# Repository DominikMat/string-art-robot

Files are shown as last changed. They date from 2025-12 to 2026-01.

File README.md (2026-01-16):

# String Art Robot

A machine to automatically draw string art designs on a circular ring of nails.

## Project Overview

**Team Members:** 
- Dominik Matuszczyk (PL)
- Dizha Oleksii (UA) 
- Tkachuk Nikita (UA)

This robot was created for the Intro to Robotics course at the University of the Aegean (Fall Semester 2025/26) during our Erasmus trips. 
The system uses a computer-generated sequence to physically wind string around a ring of nails to create geometric patterns.

---

## Links & Media
To see our creation you can view our presentation file or our video presentation (made because of bad weather on Samos island on the day of class)
* Project Presentation: https://docs.google.com/presentation/d/1VIfVSTO9Wcaq9Rl0Zi-_Bw-y_5G3Nwj30t2qu21ZTrM/edit?usp=sharing
* Demo Video: https://drive.google.com/file/d/1XwlmAQR4rs1_c6xqZL0Uokjqz6scIsDI/view?usp=drivesdk
* Demo Video YouTube (if above not working): https://youtu.be/TUs5X3Doydk
---

## 🔌 Hardware Wiring
The wiring involves connecting the Servo directly to the Pico and the Stepper Motor via the ULN2003 driver chip.

### Wiring Diagram Table

| Servo connections | Servo Wire colour | Pico Pin | Description |
| :--- | :--- | :--- | :--- |
| (MG996R) | Orange (Signal) | Pico GP16 | PWM Control |
| | Red (VCC) | Pico VBUS | 5V Power |
| | Brown (GND) | Pico GND | Ground |

| Stepper Driver chip connections | ULM Chip Input | Pico Pin | Description |
| :--- | :--- | :--- | :--- |
| (ULN2003) | Pin 1 (IN1) | GP18 | Input for Coil A |
| (Pico to Driver)| Pin 2 (IN2) | GP19 | Input for Coil B |
| | Pin 3 (IN3) | GP20 | Input for Coil C |
| | Pin 4 (IN4) | GP21 | Input for Coil D |
| | Pin 8 (-) | GND | Ground |
| | Pin 9 (+) | VBUS | 5V Power |

| Stepper Motor connections | Stepper Wire colour | ULM Chip Output | Description |
| :--- | :--- | :--- | :--- |
| (28BYJ-48) | Blue | Pin 16 (OUT1) | Coil A |
| (Stepper to driver) | Pink | Pin 15 (OUT2) | Coil B |
| | Yellow | Pin 14 (OUT3) | Coil C |
| | Orange | Pin 13 (OUT4) | Coil D |
| | Red | Pico VBUS | 5V Power |

---

## 🛠️ Software Installation & Setup

To run the robot, you need to set up the PlatformIO environment in VS Code.

### Step 1: Install VS Code & PlatformIO
1. Download and install Visual Studio Code.
2. Open VS Code, go to the Extensions tab (Ctrl+Shift+X).
3. Search for "PlatformIO IDE" and click Install.
4. Restart VS Code once the installation is complete.

### Step 2: Import / Create the Project
To be able to flash the code you can either import or create a PlatformIO project.

IMPORT
1. Download this repository and unzip
2. In the VS Code extension bar click PlatformIO (alien) icon
3. Navigate to Quick Access / PIO Home / Open and click
4. Click the 'Import Arduino Project' Button
5. Choose 'Raspberry Pi Pico' board and the unziped repository directory

CREATE NEW
1. Click the PlatformIO (Alien icon) on the left sidebar.
2. In the VS Code extension bar click PlatformIO (alien) icon
3. Navigate to Quick Access / PIO Home / Open and click
4. Click 'New Project'
3. Name: StringArtRobot
4. Board: Raspberry Pi Pico
5. Framework: Arduino
6. Click Finish.

### Step 3: Configure platformio.ini
If you have created your project as a 'New Project' and not imported it,
make sure the plaformio.ini file matches the configuration below.

```
[env:pico]
platform = raspberrypi
board = pico
framework = arduino
lib_deps = 
    arduino-libraries/Servo@^1.3.0
```

### Step 4: Flash the Code and initalize the board
1. Connect your Raspberry Pi Pico W to the computer via USB.
2. The check button on the bottom of VS Code validates your code (you can immidiately flash the board, but this is faster in case of errors)
3. Flash the Pico board memory with the Right Arrow Icon on the bottom status bar and wait until complete.
4. If successful your Pico board should automatically start executing the code
5. For the initalization protocol of the robot in this project you must next open the serial monitor (the plug icon on the bottom status bar), and then click enter to progress through the steps.
   
---

## 🎨 Pattern Generation (Python)

1. Navigate to the src/ folder.
2. Run: python string_visualizer.py (if you dont have you must install Python 3)
3. The program will display the design in a window. Press SPACE or ENTER to cycle through patterns.
4. The numerical nail sequence will print to your terminal.
5. Copy that sequence and paste it into the "nailSequence" array in your main.cpp before flashing.

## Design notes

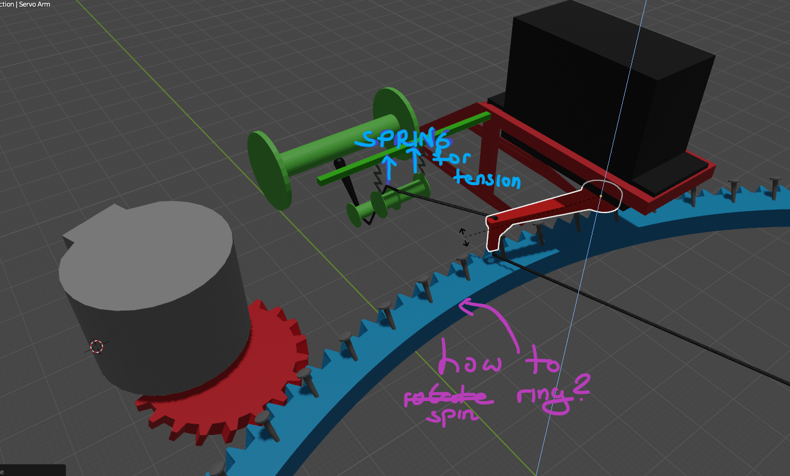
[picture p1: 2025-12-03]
blender files/blender-first-design.png

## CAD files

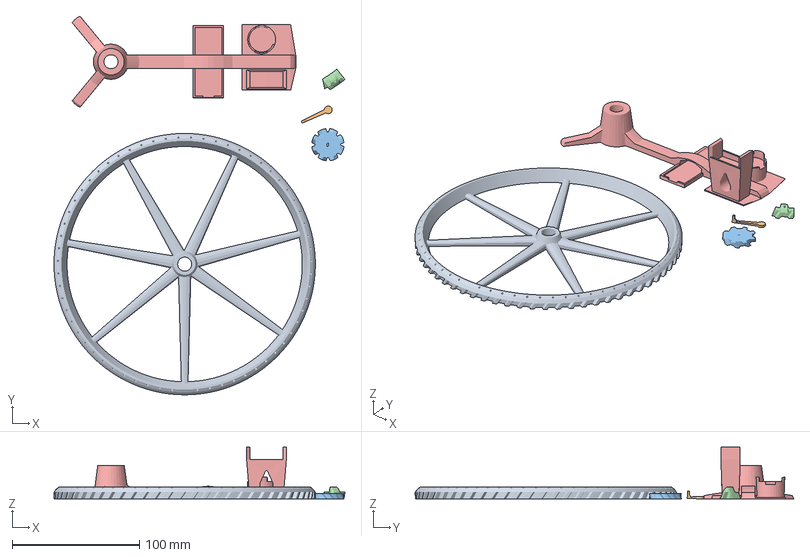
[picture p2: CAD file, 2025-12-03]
3d-print files/CCR6SE_stand-complete-test.3mf
228.9 x 297.8 x 40.5 mm
nail-ring-complete-test.stl
servo-arm.stl
motor-gear.stl
ring-test-piece.stl
stand-complete-test.stl

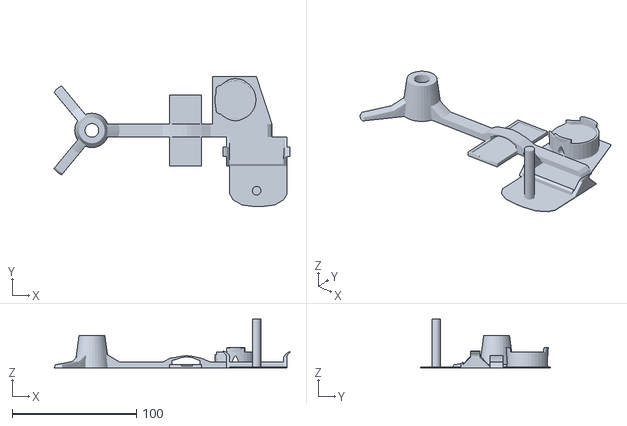
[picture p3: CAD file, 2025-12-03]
3d-print files/stand-complete.stl
190.2 x 104.8 x 39.4

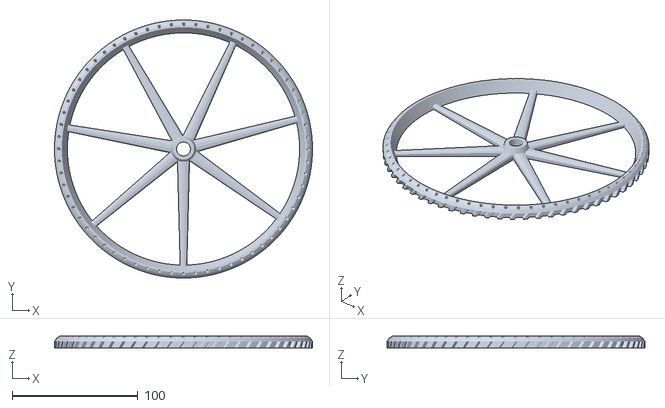
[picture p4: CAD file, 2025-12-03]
3d-print files/nail-ring-complete.stl
205.6 x 205.6 x 9.33

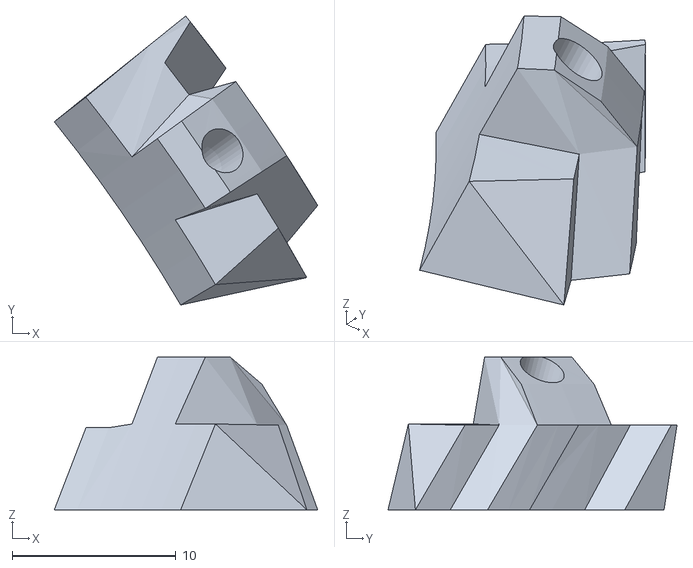
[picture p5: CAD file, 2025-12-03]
3d-print files/ring-test-piece.stl
16.1 x 17.7 x 9.33

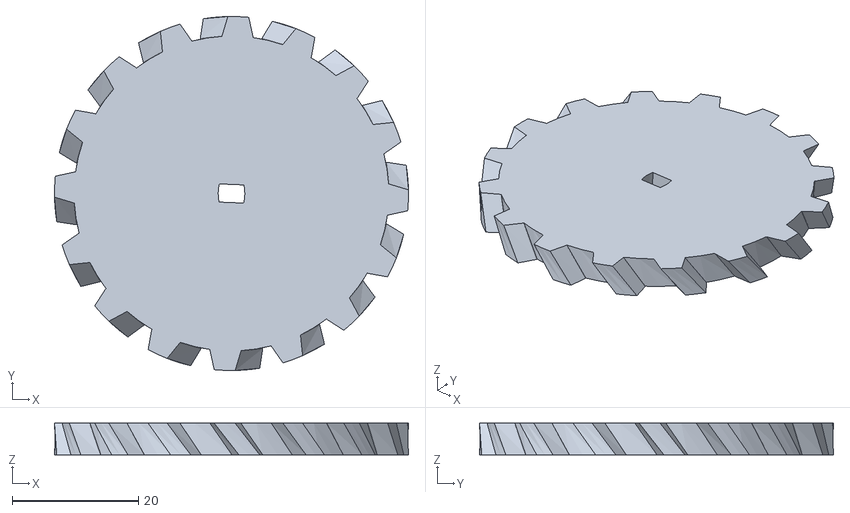
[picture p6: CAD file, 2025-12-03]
3d-print files/motor-gear.stl
56.0 x 56.0 x 5.00

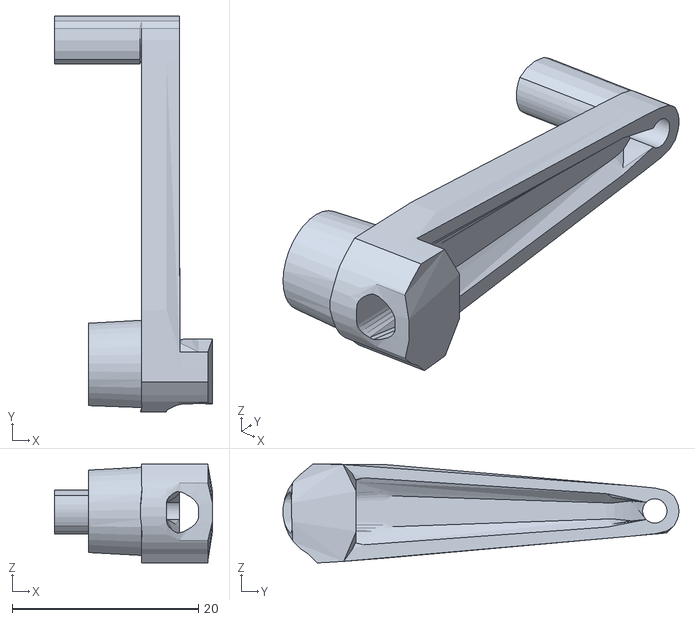
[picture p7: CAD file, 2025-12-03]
3d-print files/servo-arm.stl
17.0 x 42.5 x 10.6

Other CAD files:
blender files/string-art-robot-model-1.blend

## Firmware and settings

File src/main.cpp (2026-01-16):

#include <Arduino.h>
#include <Servo.h>

/* Ring variables */
const int num_nails = 32; 

/* Stepper variables */
const int motorPin1 = 18; // Blue (IN1)
const int motorPin2 = 19; // Pink (IN2)
const int motorPin3 = 20; // Yellow (IN3)
const int motorPin4 = 21; // Orange (IN4)
const int stepper_steps_per_ring_rotation = 4096*4; // 4 to 1 reducion from stepper to ring, stepper has 2048 steps with half-step sequencing
const int steps_per_nail = stepper_steps_per_ring_rotation / num_nails; // divides cleanly to 512 (32 nails)
const int target_stepper_rpm = 10;
const int step_delay_microseconds = (60/target_stepper_rpm) * 1000 * 1000 / 4096; // calculate delay in um  
int current_ring_step_position = 0;

/* Servo variables */
const int servoPin = 16; 
const int servo_middle_angle = 90;
const int servo_rotation_angle_span = 60;
const int servo_inside_angle = servo_middle_angle + servo_rotation_angle_span/2;
const int servo_outside_angle = servo_middle_angle - servo_rotation_angle_span/2;
const int SERVO_DELAY_MS = 500;

Servo myServo;
int current_servo_angle = 90;
int current_step_index = 0;

const int double_bounce_star_sequence[] = { 0, 11, 28, 7, 24, 3, 20, 31, 16, 27, 12, 23, 8, 19, 4, 15, 0 };
const int double_bounce_star_sequence_len = 17;

// Sekwencja Half-step (8 kroków) - Działająca wersja
const int lookup[8][4] = {
  {1, 0, 0, 0}, {1, 1, 0, 0}, {0, 1, 0, 0}, {0, 1, 1, 0},
  {0, 0, 1, 0}, {0, 0, 1, 1}, {0, 0, 0, 1}, {1, 0, 0, 1}
};

void rotate_ring(int steps, bool anti_clockwise = true) {
    for (int i = 0; i < steps; i++) {
        // one stepper step sequence
        digitalWrite(motorPin1, lookup[current_step_index][0]);
        digitalWrite(motorPin2, lookup[current_step_index][1]);
        digitalWrite(motorPin3, lookup[current_step_index][2]);
        digitalWrite(motorPin4, lookup[current_step_index][3]);

        current_step_index = (current_step_index + (anti_clockwise ? 1 : 7)) % 8; 
        current_ring_step_position = (current_ring_step_position + (anti_clockwise ? 1 : (stepper_steps_per_ring_rotation-1))) % stepper_steps_per_ring_rotation; 
        
        delayMicroseconds(step_delay_microseconds);
    }
}

void moveServo(int targetAngle) {
    if (targetAngle < 0 || targetAngle > 180) {
        Serial.println("Error: angle outside range (0-180deg).");
        return;
    }
    
    // smoothly rotate to target angle
    int step_direction = (targetAngle > current_servo_angle) ? 1 : -1;
    while (current_servo_angle != targetAngle) {
        current_servo_angle += step_direction;
        myServo.write(current_servo_angle);
        delay(5);
    }
    
    delay(SERVO_DELAY_MS);
}

void wait_for_user_confirm() {
    Serial.println("    Confirm goto next setp: (any key): ");
    while (!Serial.available()); // wait until serial input 
    while (Serial.available()) Serial.read(); // clear input buffer
    Serial.println("    Continuing program ...");
}

void rotate_ring_to_nail(int nail_idx) {
    int target_pos = nail_idx * steps_per_nail;
    
    int diff = target_pos - current_ring_step_position;
    if (diff > stepper_steps_per_ring_rotation / 2) diff -= stepper_steps_per_ring_rotation;
    if (diff < -stepper_steps_per_ring_rotation / 2) diff += stepper_steps_per_ring_rotation;

    rotate_ring(abs(diff), diff > 0);
}

// ...

void plot_around_nail (int nail_idx) {
    rotate_ring_to_nail (nail_idx);
    moveServo (servo_outside_angle);
    rotate_ring_to_nail ( (nail_idx+1) % num_nails );
    moveServo (servo_inside_angle);
}

// ...

void setup() {
  Serial.begin(115200);
  while(!Serial);

  pinMode(motorPin1, OUTPUT);
  pinMode(motorPin2, OUTPUT);
  pinMode(motorPin3, OUTPUT);
  pinMode(motorPin4, OUTPUT);

  myServo.attach(servoPin);
  
    // initalize program
    wait_for_user_confirm(); 

    //remove ring    
    Serial.println("");
    Serial.println("Please make sure the nail ring or servo arm is removed");
    wait_for_user_confirm();

    Serial.println("");
    Serial.println("Servo position max anti-clockwise - 0deg");
    moveServo(0); 
    delay(500);
    Serial.println("Servo position max clockwise - 180deg");
    moveServo(180); 
    delay(500);
    Serial.println("Servo position middle - 90deg");
    moveServo(90); 
    delay(500);
    
    Serial.println("");
    Serial.println("Please configure the servo-arm and nail ring to the inital position");
    wait_for_user_confirm();
    delay(1000);
}

void loop() {
    
    Serial.print("");
    moveServo(servo_inside_angle); 
    rotate_ring_to_nail (double_bounce_star_sequence[1]);
    Serial.println("Please attach the string to the starting nail");
    Serial.println("  the nail under the servo arm is number 0");
    Serial.print("  "); Serial.print(double_bounce_star_sequence[1]); Serial.println(" counting counter-clockwise");
    Serial.print("  "); Serial.print(num_nails - double_bounce_star_sequence[1]); Serial.println(" counting clockwise");
    wait_for_user_confirm();
    
    Serial.print("");
    Serial.println("STARTING DRAWING");

    for (int i=1; i<double_bounce_star_sequence_len; i++) {
        Serial.print("    going to next nail - num ");
        Serial.println(double_bounce_star_sequence[i]);

        plot_around_nail ( double_bounce_star_sequence[i] );
    }

    Serial.println("DRAWING COMPLETE");

    while (true) {
        delay(10000); 
    }
}

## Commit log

2025-12-03 3d print files
    [CCR6SE_stand-complete-test.3mf, motor-gear.stl, nail-ring-complete.stl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]
2025-12-03 Add README for String Art Robot project
    Added a README file detailing the String Art Robot project, including sections on the sequence visualizer, robot mechanics, gearing, and presentation.
2026-01-16 Revise README for clarity and wiring instructions
    Updated README to improve clarity and add hardware wiring details.
2026-01-16 chagne string visualizer language
    [string-art-robot-model-1.blend]
